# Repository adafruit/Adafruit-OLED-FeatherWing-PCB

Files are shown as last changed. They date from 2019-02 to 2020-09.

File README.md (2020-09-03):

## Adafruit FeatherWing OLED - 128x32 and 128x64 OLED Add-on For Feather PCB
<a href="http://www.adafruit.com/products/2900"><br/>
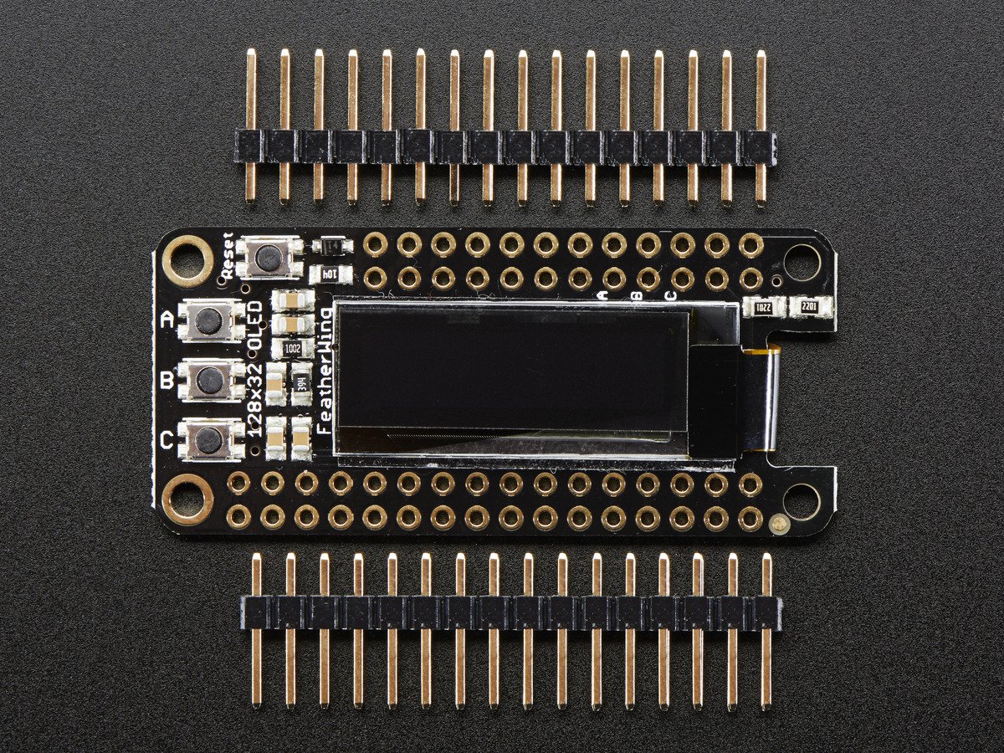
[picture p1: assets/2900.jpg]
<a href="http://www.adafruit.com/products/2900"><br/>
Click here to purchase one from the Adafruit shop</a>

PCB files for the Adafruit FeatherWing OLED - 128x32 OLED Add-on For Feather. Format is EagleCAD schematic and board layout
* https://www.adafruit.com/product/2900

and for Adafruit FeatherWing OLED - 128x64 OLED Add-on For Feather - STEMMA QT / Qwiic
* https://www.adafruit.com/product/4650

### Description

A Feather board without ambition is a Feather board without FeatherWings! This is the **FeatherWing OLED**: it adds a 128x32 or 128x64 monochrome OLED plus 3 user buttons to any Feather main board. Using our [Feather Stacking Headers](https://www.adafruit.com/products/2830) or [Feather Female Headers](http://www.adafruit.com/products/2886) you can connect a FeatherWing on top of your Feather board and let the board take flight!

These displays are small, only about 1"-1.3" diagonal, but very readable due to the high contrast of an OLED display. This screen is made of 128x32 individual white OLED pixels and because the display makes its own light, no backlight is required. This reduces the power required to run the OLED and is why the display has such high contrast; we really like this miniature display for its crispness! We also toss on a reset button and three mini tactile buttons called A B and C so you can add a mini user interface to your feather.

The 128x64 display is an SH1107, which uses only I2C so you can easily connect it up with just two pins used (plus power and ground!).  There's an auto-reset circuit and a reset button on the top. We've even included a SparkFun qwiic-compatible STEMMA QT connector for the I2C bus so you can plug and play any of our STEMMA QT, qwiic or Grove I2C sensors and devices!

Tested working with **all Feather boards**. The OLED uses only the two I2C pins on the Feather, and you can pretty much stack it with any other FeatherWing, even ones that use I2C since that is a shared bus. To use, [Check out our tutorial ! It has schematics, datasheets, files, and code examples.](https://learn.adafruit.com/adafruit-oled-featherwing/download)

[Check out our range of Feather boards here.](https://www.adafruit.com/feather)

### License

Adafruit invests time and resources providing this open source design, please support Adafruit and open-source hardware by purchasing products from [Adafruit](https://www.adafruit.com)!

Designed by Limor Fried/Ladyada for Adafruit Industries.

Creative Commons Attribution/Share-Alike, all text above must be included in any redistribution. See license.txt for additional details.

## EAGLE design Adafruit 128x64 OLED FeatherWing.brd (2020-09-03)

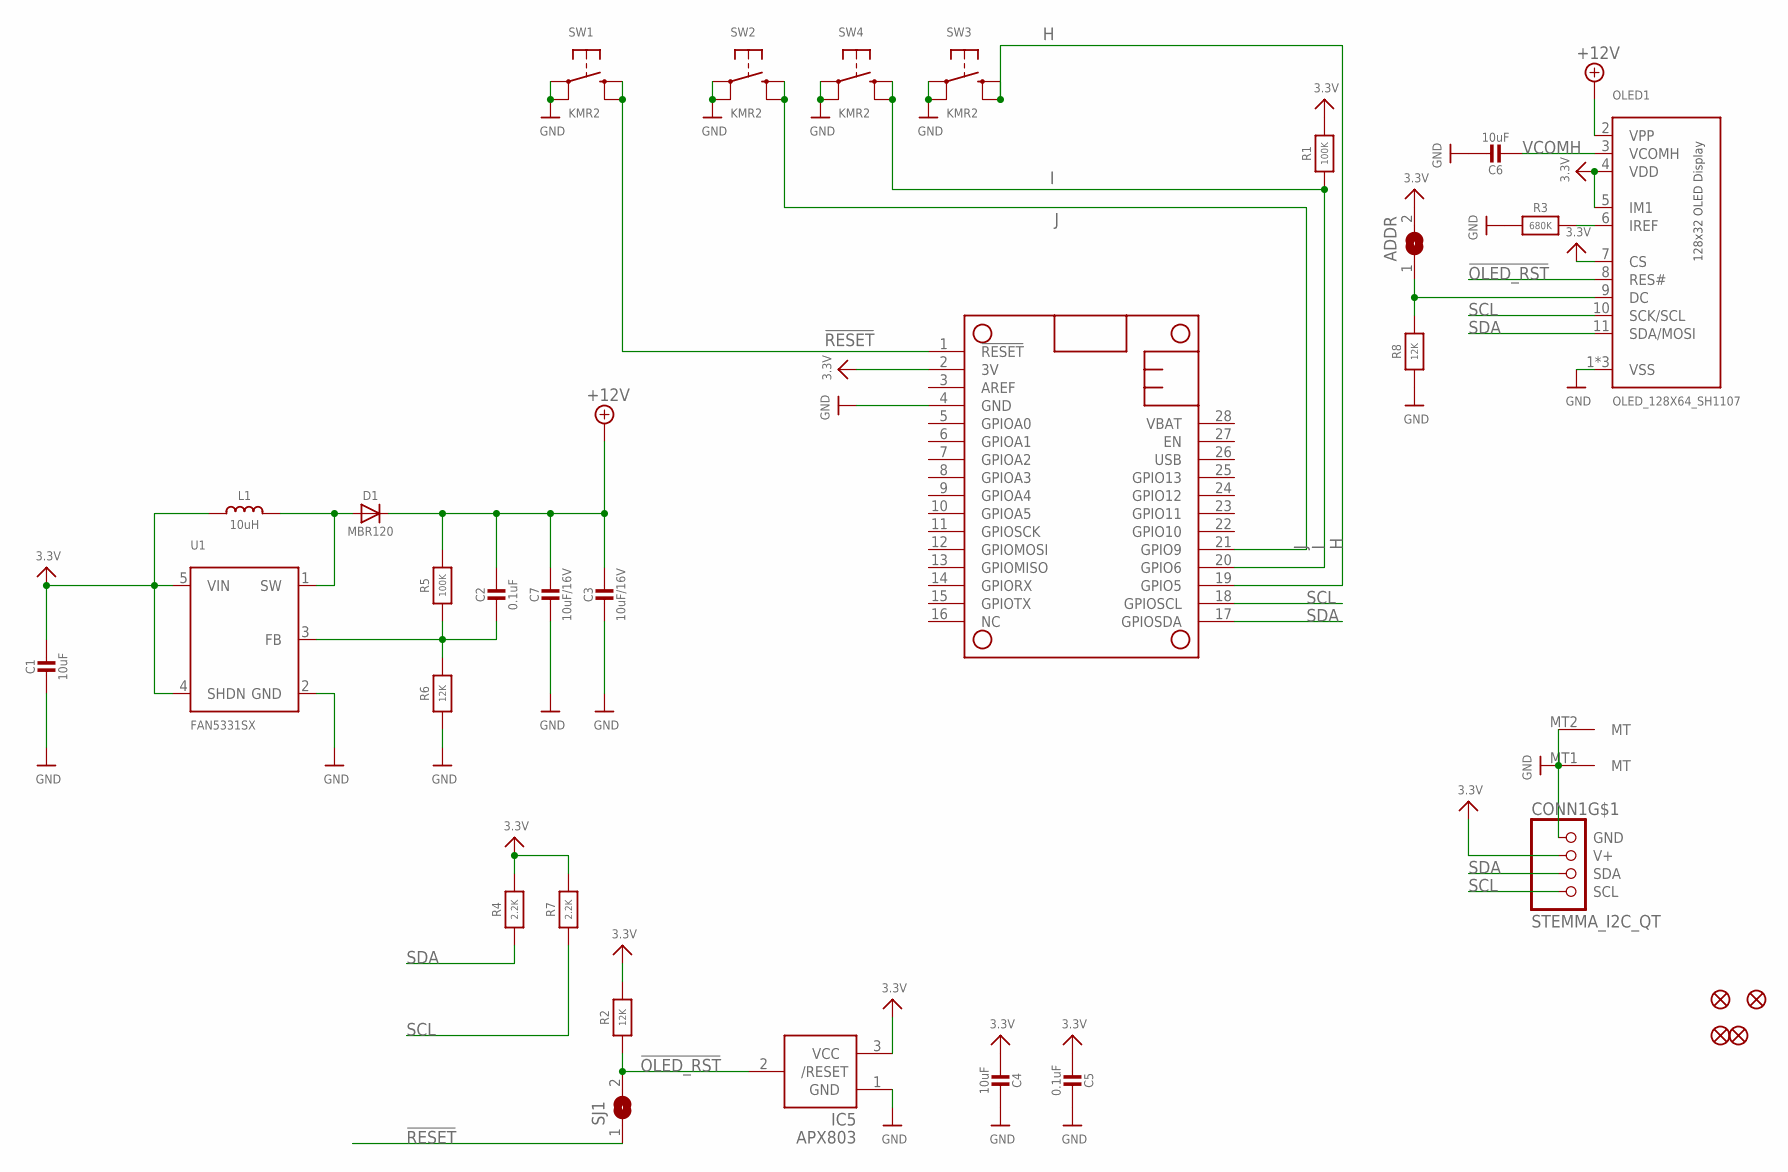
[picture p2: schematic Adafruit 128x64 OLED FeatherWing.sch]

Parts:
ADDR: SOLDERJUMPER; SOLDERJUMPER_ARROW_NOPASTE
C1, C4, C6: 10uF; 0805-NO
C2, C5: 0.1uF; 0603-NO
C3, C7: 10uF/16V; 0805-NO
CONN1: STEMMA_I2C_QT; JST_SH4
D1: MBR120; SOD-123
FID1, FID2, FID3, FID4: FIDUCIAL_1MM
IC5: APX803; SOT23
L1: 10uH; INDUCTOR_1007
MS1: FEATHERWING_NODIM
OLED1: OLED_128X64_SH1107; QT1107P11A
R1, R5: 100K; 0603-NO
R2, R6, R8: 12K; 0603-NO
R3: 680K; 0603-NO
R4, R7: 2.2K; 0603-NO
SJ1: SOLDERJUMPERCLOSED; SOLDERJUMPER_CLOSEDWIRE
SW1, SW2, SW3, SW4: KMR2; BTN_KMR2_4.6X2.8
U1: FAN5331SX; SOT23-5

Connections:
3.3V: ADDR.2, C1.1, C4.2, C5.2, CONN1.2 (V+), IC5.3 (VCC), L1.P$1 (1), MS1.2 (3V), OLED1.4 (VDD), OLED1.5 (IM1), OLED1.7 (CS), R1.2, R2.2, R4.2, R7.2, U1.4 (SHDN), U1.5 (VIN)
!OLED_RST: IC5.2 (/RESET), OLED1.8 (RES#), R2.1, SJ1.2
!RESET: MS1.1 (!RESET), SJ1.1, SW1.B (S), SW1.B' (S1)
+12V: C2.1, C3.1, C7.1, D1.C, OLED1.2 (VPP), R5.2
GND: C1.2, C3.2, C4.1, C5.1, C6.1, C7.2, CONN1.1 (GND), CONN1.MT1 (MT), CONN1.MT2 (MT), IC5.1 (GND), MS1.4 (GND), OLED1.1 (VSS), OLED1.12 (VSS), OLED1.13 (VSS), R3.1, R6.1, R8.1, SW1.A, SW1.A' (P1), SW2.A, SW2.A' (P1), SW3.A, SW3.A' (P1), SW4.A, SW4.A' (P1), U1.2 (GND)
H: MS1.19 (GPIO5), SW3.B (S), SW3.B' (S1)
I: MS1.20 (GPIO6), R1.1, SW4.B (S), SW4.B' (S1)
J: MS1.21 (GPIO9), SW2.B (S), SW2.B' (S1)
unnamed: D1.A, L1.P$2 (2), U1.1 (SW)
unnamed: ADDR.1, OLED1.9 (DC), R8.2
unnamed: C2.2, R5.1, R6.2, U1.3 (FB)
unnamed: OLED1.6 (IREF), R3.2
SCL: CONN1.4 (SCL), MS1.18 (GPIOSCL), OLED1.10 (SCK/SCL), R7.1
SDA: CONN1.3 (SDA), MS1.17 (GPIOSDA), OLED1.11 (SDA/MOSI), R4.1
VCOMH: C6.2, OLED1.3 (VCOMH)

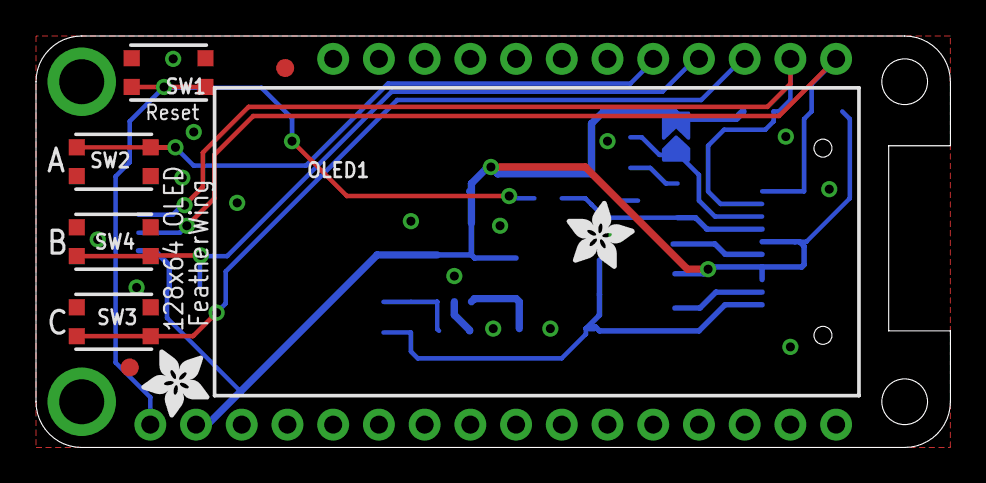
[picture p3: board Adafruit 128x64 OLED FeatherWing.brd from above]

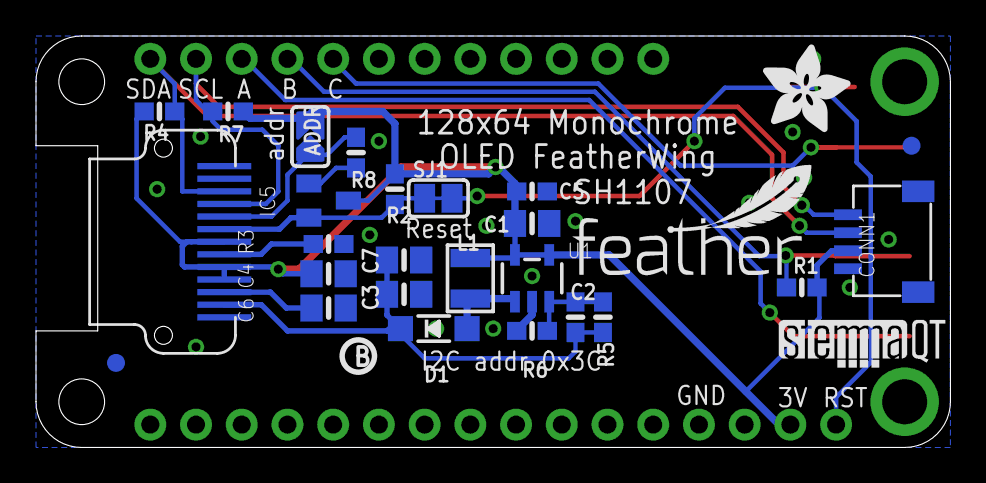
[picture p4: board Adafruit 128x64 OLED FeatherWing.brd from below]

Board: 2 copper layers, 50.8 x 22.9 mm, 38 parts (28 on the bottom side), 15 nets.

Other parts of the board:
U$8: ADAFRUIT_5MM
U$14: PCBFEAT-REV-040
U$16, U$37: ADAFRUIT_3.5MM
U$35: STEMMAQT
U$36: FEATHERLOGO_SMALL

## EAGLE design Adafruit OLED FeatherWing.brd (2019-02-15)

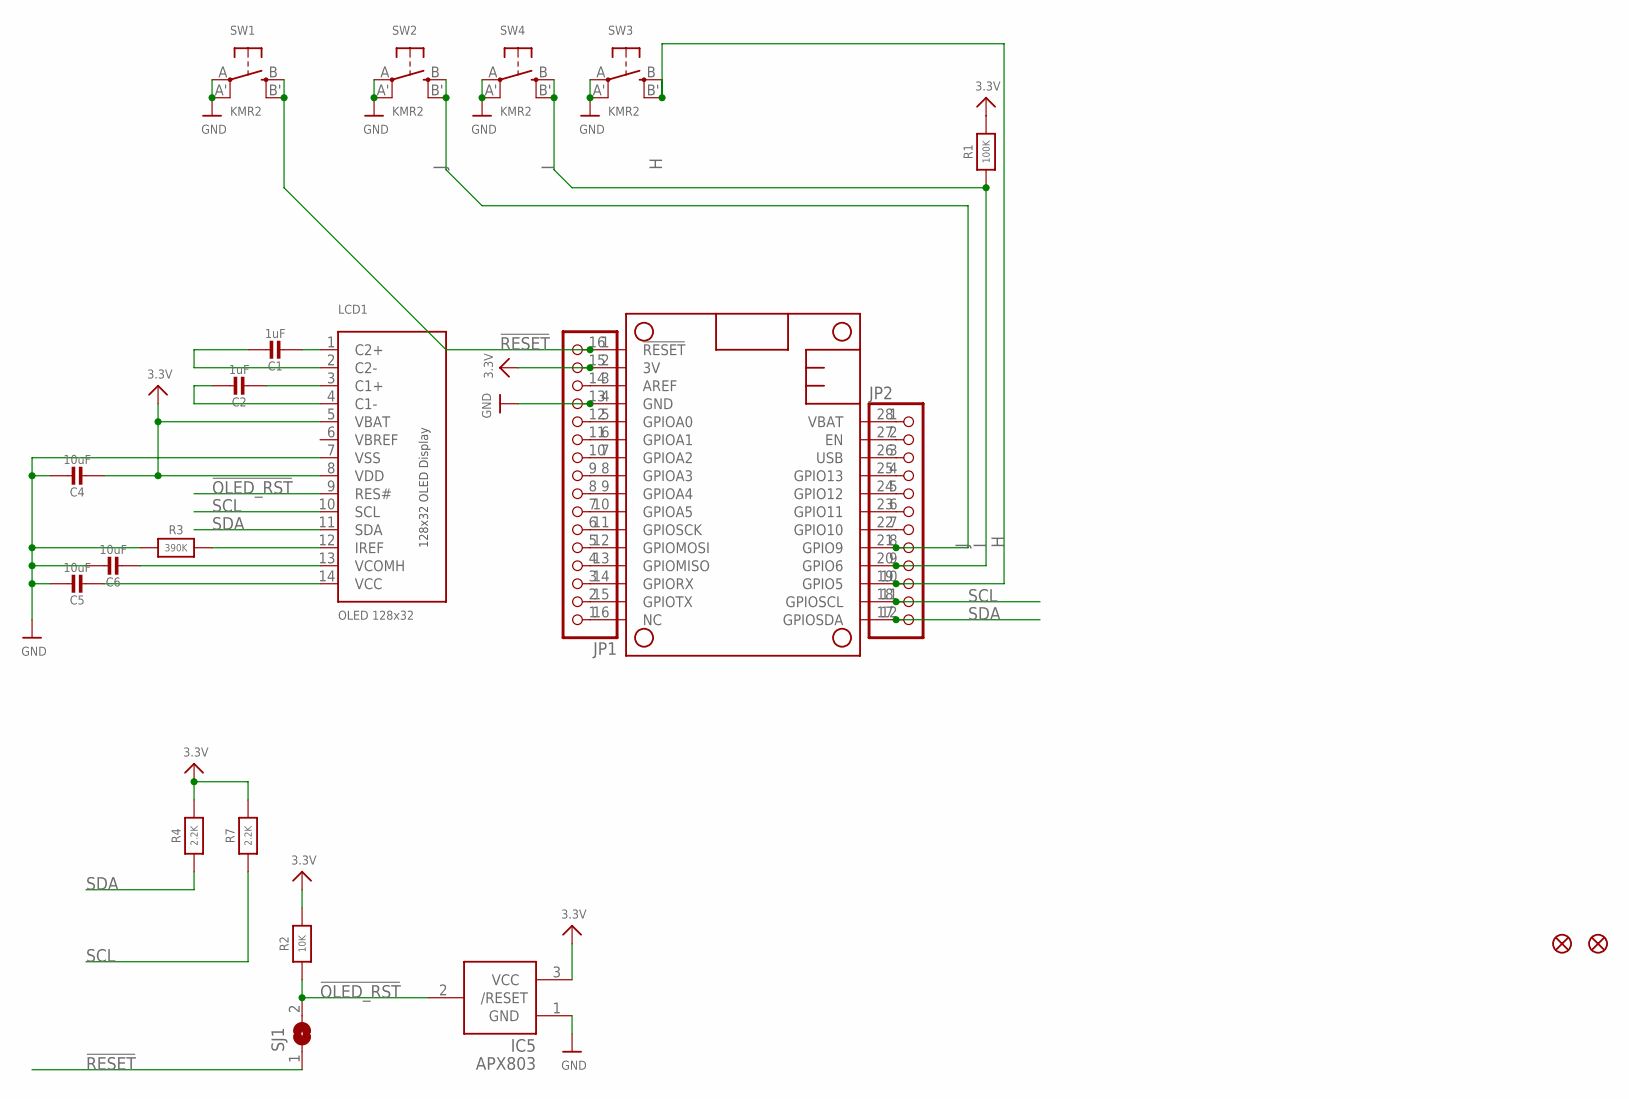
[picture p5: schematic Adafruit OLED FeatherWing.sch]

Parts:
C1, C2: 1uF; 0805-NO
C4, C5, C6: 10uF; 0805-NO
FID1, FID2: FIDUCIAL""; FIDUCIAL_1MM
IC5: APX803; SOT23
JP1: HEADER-1X16ROUND; 1X16_ROUND
JP2: HEADER-1X12; 1X12_ROUND
LCD1: OLED 128x32; UG-2832HSWEG02_WRAPUNDER
MS1: FEATHERWING
R1: 100K; 0805-NO
R2: 10K; _0805MP
R3: 390K; 0805-NO
R4, R7: 2.2K; 0805-NO
SJ1: SOLDERJUMPER; SOLDERJUMPER_ARROW_NOPASTE
SW1, SW2, SW3, SW4: KMR2; BTN_KMR2_4.6X2.8

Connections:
3.3V: C4.2, IC5.3 (VCC), JP1.15, LCD1.5 (VBAT), LCD1.8 (VDD), MS1.2 (3V), R1.2, R2.2, R4.2, R7.2
!OLED_RST: IC5.2 (/RESET), LCD1.9 (RES#), R2.1, SJ1.2
!RESET: JP1.16, MS1.1 (!RESET), SJ1.1, SW1.B (S), SW1.B' (S1)
A: JP1.12, MS1.5 (GPIOA0)
AREF: JP1.14, MS1.3 (AREF)
B: JP1.11, MS1.6 (GPIOA1)
C: JP1.10, MS1.7 (GPIOA2)
D: JP1.9, MS1.8 (GPIOA3)
E: JP1.8, MS1.9 (GPIOA4)
EN: JP2.2, MS1.27 (EN)
F: JP1.7, MS1.10 (GPIOA5)
G: JP1.1, MS1.16 (NC)
GND: C4.1, C5.1, C6.1, IC5.1 (GND), JP1.13, LCD1.7 (VSS), MS1.4 (GND), R3.1, SW1.A, SW1.A' (P1), SW2.A, SW2.A' (P1), SW3.A, SW3.A' (P1), SW4.A, SW4.A' (P1)
H: JP2.10, MS1.19 (GPIO5), SW3.B (S), SW3.B' (S1)
I: JP2.9, MS1.20 (GPIO6), R1.1, SW4.B (S), SW4.B' (S1)
J: JP2.8, MS1.21 (GPIO9), SW2.B (S), SW2.B' (S1)
K: JP2.7, MS1.22 (GPIO10)
L: JP2.6, MS1.23 (GPIO11)
M: JP2.5, MS1.24 (GPIO12)
MISO: JP1.4, MS1.13 (GPIOMISO)
MOSI: JP1.5, MS1.12 (GPIOMOSI)
N: JP2.4, MS1.25 (GPIO13)
unnamed: C1.2, LCD1.1 (C2+)
unnamed: C1.1, LCD1.2 (C2-)
unnamed: C2.2, LCD1.3 (C1+)
unnamed: C2.1, LCD1.4 (C1-)
unnamed: C6.2, LCD1.13 (VCOMH)
unnamed: C5.2, LCD1.14 (VCC)
unnamed: LCD1.12 (IREF), R3.2
RX: JP1.3, MS1.14 (GPIORX)
SCK: JP1.6, MS1.11 (GPIOSCK)
SCL: JP2.11, LCD1.10 (SCL), MS1.18 (GPIOSCL), R7.1
SDA: JP2.12, LCD1.11 (SDA), MS1.17 (GPIOSDA), R4.1
TX: JP1.2, MS1.15 (GPIOTX)
USB: JP2.3, MS1.26 (USB)
VBAT: JP2.1, MS1.28 (VBAT)
VBREF: LCD1.6 (VBREF)

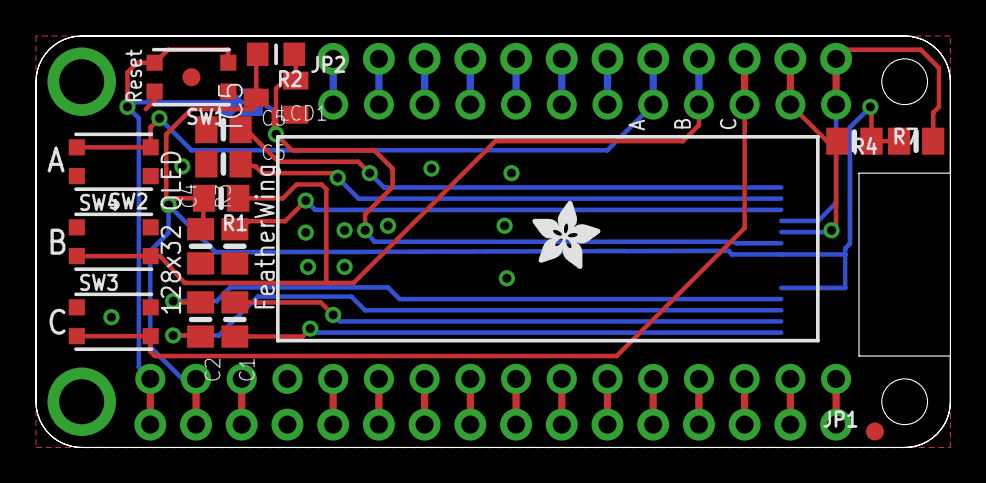
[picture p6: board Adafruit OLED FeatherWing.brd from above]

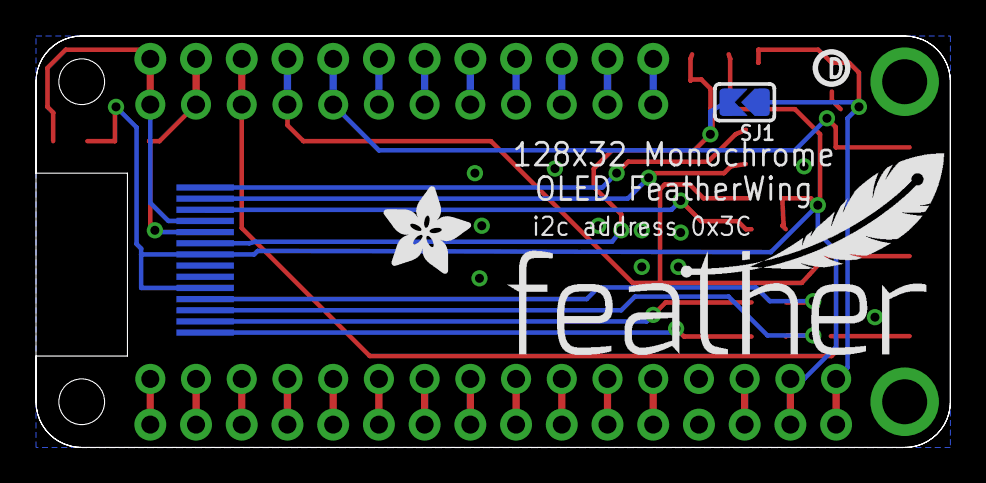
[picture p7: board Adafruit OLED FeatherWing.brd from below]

Board: 2 copper layers, 50.8 x 22.9 mm, 26 parts (4 on the bottom side), 36 nets.

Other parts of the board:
U$4: FEATHERLOGO
U$8: ADAFRUIT_5MM
U$14: PCBFEAT-REV-040
U$16: ADAFRUIT_3.5MM

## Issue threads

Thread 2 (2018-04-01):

Incompatibility with 3406 (nrf52 feather)

iprepiprep, 2018-04-01:
Hi shield has Button A connected to P0.31/A7 on the nrf52 Feather (3406). 3406 Uses it to measure battery voltage. As a result the push button cannot be used.

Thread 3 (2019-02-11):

Not the recent version.

vogt31337, 2019-02-11:
Hi,

As stated here [Issue somewhere else](https://github.com/adafruit/Adafruit_CircuitPython_SSD1306/issues/7#issuecomment-355622748), the board has been updated. Some picture show the new version, recognizable by a three legged transistor-thing right next to the reset button.
But the new schematics are nowhere to be found. Only for the old version which has a diode at that spot.

Was this just a package change (three legged diode?) or as stated in the other Issue "a little resetter chip"? And how do I interface it?

Because shutting off the display and trying to turn it on only works with a hard reset...

kattni, 2019-02-16:
Hello! We've updated the PCB files in this repo to the current version, as well as the schematic on the associated Learn guide.

Closed 2019-02-16.

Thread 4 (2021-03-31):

128x64 OLED FeatherWing resets during operation as battery-powered Stemma-QT device

CedarGroveStudios, 2021-03-31:

CedarGroveStudios, 2021-03-31:
This was caused primarily by battery capacity limitations.

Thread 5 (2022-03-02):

128x64 - Incorrect Button Labels

nicholaswilde, 2022-03-02:
On the 128x64 OLED, comparing the button labels (A, B, & C) with the pin labels, they seems to be inconsistent. Button B is correct but buttons A & C are flipped. Button A is mapped to pin C (21 J) and Button C is mapped to pin A (19 H).

This has been confirmed by testing the physical OELD screen as well as looking at the schematics.

ladyada, 2022-03-04:
yes this is documented here
https://learn.adafruit.com/adafruit-128x64-oled-featherwing/pinouts#optional-buttons-3071174-9

nicholaswilde, 2022-03-04:
Bah, I should have read the docs. Thanks for the response and the hard work.

ladyada, 2022-03-04:
all good, we'll fix on the next PCB order :)

Closed 2022-03-04.

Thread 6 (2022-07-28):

Excessive fragility of the oled panel and proposition

dombru54, 2022-07-28:
Hello,
The upper glass of the oled panel is cantilevered, on the side of pcb flex.
The simple fact of holding the card in my hands caused a crack visible only with the binocular, which made me lose several days of diagnostics.
The other manufacturers, after self-gluing the panel, deposit resin between the pcb and the upper glass, especially in the corners.

ladyada, 2022-07-29:
the glass does not overhang, and OLEDs are very delicate - we'll look at adding resin but it would not be instant as we dont have any kind of resin machine

dombru54, 2022-07-29:
Hello Ladyada,

Thank you for all your answers.

I have been working with oled screens for several years.
Your panel upper glass overhang of 3.3 mm compared to the lower glass to the flex side.

I have a project to make a featherwing with PMW3901 (flowMotion) and VL53L0X (laser rangefinder) used in drones like "Flow Breakout Bitcraze"
https://www.bitcraze.io/products/old-products/flow-breakout/
Can we collaborate on this project ?

Sorry for my english, i'm a french engineer ... ;>) ...

De: "ladyada" ***@***.***>
À: "adafruit/Adafruit-OLED-FeatherWing-PCB" ***@***.***>
Cc: "dombru54" ***@***.***>, "Author" ***@***.***>
Envoyé: Vendredi 29 Juillet 2022 16:58:56
Objet: Re: [adafruit/Adafruit-OLED-FeatherWing-PCB] Excessive fragility of the oled panel and proposition (Issue #6)

the glass does not overhang, and OLEDs are very delicate - we'll look at adding resin but it would not be instant as we dont have any kind of resin machine

—
Reply to this email directly, [ https://github.com/adafruit/Adafruit-OLED-FeatherWing-PCB/issues/6#issuecomment-1199466923 | view it on GitHub ] , or [ https://github.com/notifications/unsubscribe-auth/A2H4PYWFC7ALVCHBZSJMR2TVWPWTBANCNFSM544BGTHA | unsubscribe ] .
You are receiving this because you authored the thread. Message ID: <adafruit/Adafruit-OLED-FeatherWing-PCB/issues/6/1199466923 @ github . com>

Closed 2022-07-29.

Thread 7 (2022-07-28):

Erroneous serigraphy of the resolution of the panel

dombru54, 2022-07-28:
Hello,
The serigraphy is 128x64 so landscape mode.
In fact, the native screen orientation is portrait.
The serigraphy should be 64x128.
I had to rewrite part of my driver in C.

ladyada, 2022-07-29:
technically yes, but the orientation is rotated so visibility is in done as 128x64, this is not an error

Closed 2022-07-29.

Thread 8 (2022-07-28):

I2C address embiguy serigraphy

dombru54, 2022-07-28:
Hello,
The I2C address serigraphy is 0x3C.
This is valid is 7-bit MSB mode.
In some driver, the mode is 8 bits so it becomes double in hexadecimal i.e. (0x3C<<1)=0x78

ladyada, 2022-07-29:
we use the 7-bit standard for indicating I2C addresses
https://learn.adafruit.com/i2c-addresses

Closed 2022-07-29.

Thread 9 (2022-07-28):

Erroneous serigraphy of the button letter

dombru54, 2022-07-28:
Hello,
If the reference is the drawing and the board edge serigraphy then buttons A and C serigraphy are reversed.

ladyada, 2022-07-29:
this is duplicate of
https://github.com/adafruit/Adafruit-OLED-FeatherWing-PCB/issues/5

Closed 2022-07-29.

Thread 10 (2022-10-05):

Improved use of 3 user buttons : A,B,C

dombru54, 2022-10-05:
Hello,
The 3 buttons seem too tight to me.
I replaced the buttons with a mini wheel: SLLB510100.
Here are some pictures of my prototype :
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
 It would be great if you could make a version with this option ... ;>) ...

dombru54, 2022-10-05:
To complete, SLLB510100 docs : pdf, step ...
https://tech.alpsalpine.com/e/products/detail/SLLB510100/
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

or/and, more ambitious, with 5-way joystick, the dimensions are compatible, 8.6x8.6 diagonal for 9.5mm free
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
https://tech.alpsalpine.com/e/products/detail/SKRHADE010/
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
PCB example ...
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
At your service

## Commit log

2019-02-15 Adding new PCB files.
    [Adafruit OLED FeatherWing.brd, Adafruit OLED FeatherWing.sch]
2019-02-15 Removing old .brd file.
    [adafruit oled featherwing.brd]
2019-02-15 removing old .sch file
    [adafruit oled featherwing.sch]
2019-07-17 updated to use cookiecutter for pcb repos
2020-09-03 Add new board files.
    [Adafruit 128x64 OLED FeatherWing.brd, Adafruit 128x64 OLED FeatherWing.sch]
